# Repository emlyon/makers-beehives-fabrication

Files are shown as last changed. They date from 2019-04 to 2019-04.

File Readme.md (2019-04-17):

# Makers' Beehive

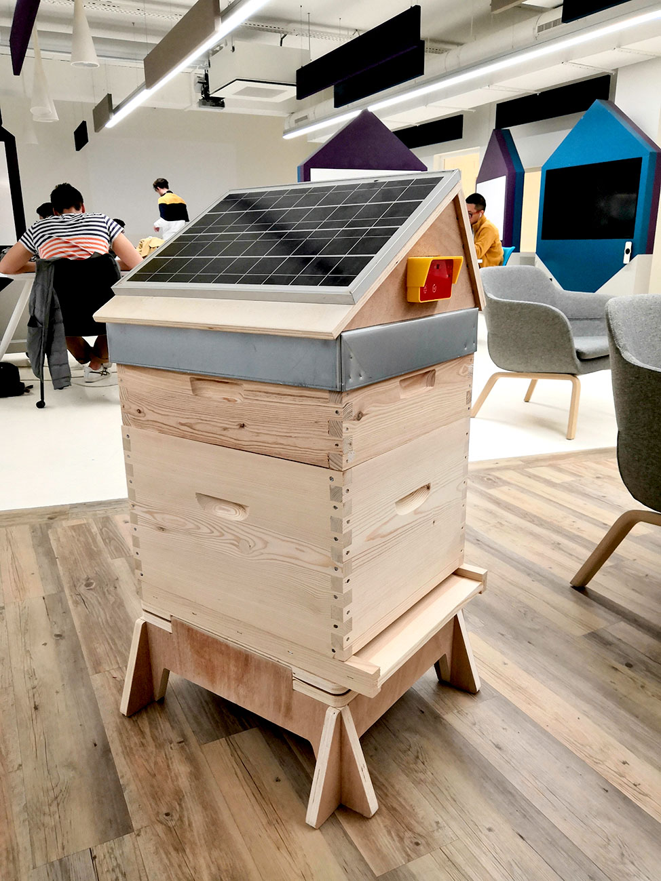
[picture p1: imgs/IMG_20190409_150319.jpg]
Makers Beehive


Makers’ Beehive is an open source beehive that was designed and
crafted at emlyon Business School’s makers’ lab during a bootcamp about IoT
by staff, students and alumni.

This project upgrades a standard dadant type beehive with load sensors on the base,
environmental sensors and camera on the roof.

More info here : [makerslab.em-lyon.com](http://makerslab.em-lyon.com/)

Makers' Beehive is licensed under the [CC by-nc-sa 4.0](https://creativecommons.org/licenses/by-nc-sa/4.0/) creative commons license



---

## Building instructions

### Electronics

Instructions for the electronics part used to monitor the activity of the beehive and the environment can be found on [this github repository](https://github.com/emlyon/makers-beehives-hardware)

---

### CNC milling

Makers Beehive has been designed to be fabricated using a CNC router with CTBX plywood 21mm.

Use a 8mm flat milling bit to cut. The [3D model](https://github.com/emlyon/makers-beehives-fabrication/blob/master/CNC%20router/makers_beehive_CNC.3dm) includes the layout for CNC milling.

We used [Autodesk Fusion 360](https://www.autodesk.com/products/fusion-360/overview) to generate the toolpaths : you can find tutorials about the _Manufacture_ feature of Fusion 360 on [Autodesk website](https://f360ap.autodesk.com/courses#creating-toolpaths-and-programs-cam).

The fusion 360 archive files are included into the [CNC router folder](https://github.com/emlyon/makers-beehives-fabrication/tree/master/CNC%20router)

---

### Assembly

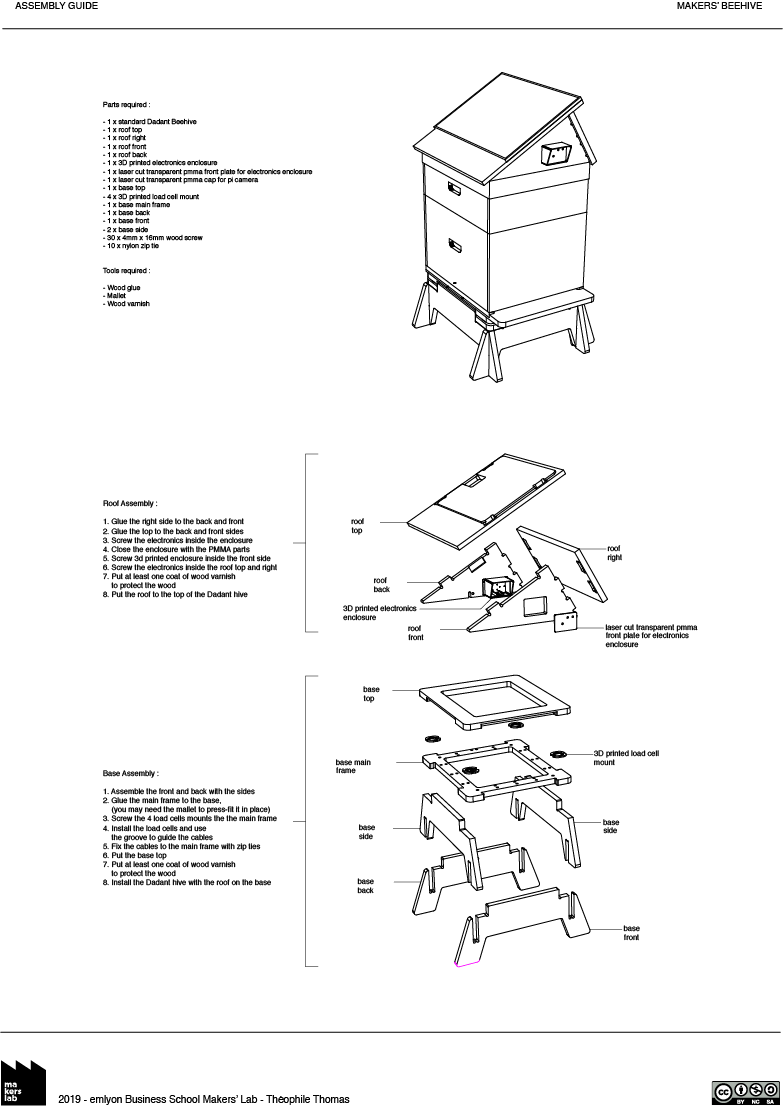
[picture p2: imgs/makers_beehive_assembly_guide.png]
Makers Beehive Assembly


A detailled list of the parts and an assembly guide can be found [in this pdf](makers_beehive_assembly_guide.pdf).

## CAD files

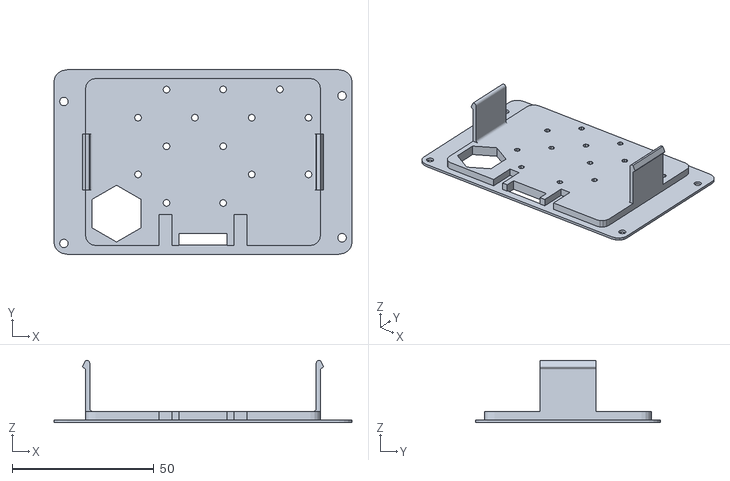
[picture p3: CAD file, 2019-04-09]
3D printing/sensor_beehive_case_base.stl
105.0 x 65.0 x 22.0

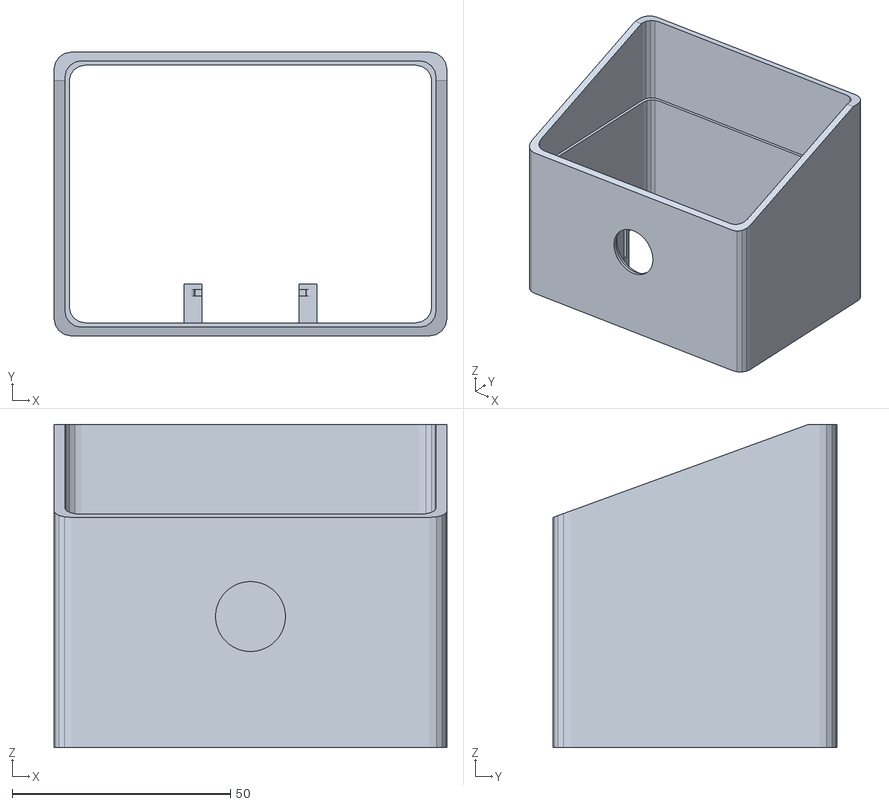
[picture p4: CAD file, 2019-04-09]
3D printing/sensor_beehive_case_top.stl
90.0 x 65.0 x 74.0

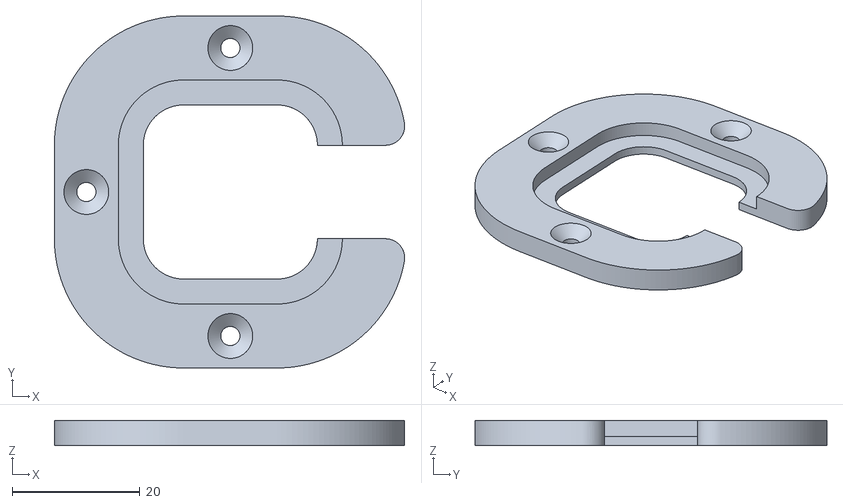
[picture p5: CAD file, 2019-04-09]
3D printing/load cell mount.stl
54.7 x 55.0 x 3.98

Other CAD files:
CNC router/baseCNC.f3d
CNC router/roofCNC.f3d

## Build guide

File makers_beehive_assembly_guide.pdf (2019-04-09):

### MAKERS’ BEEHIVE

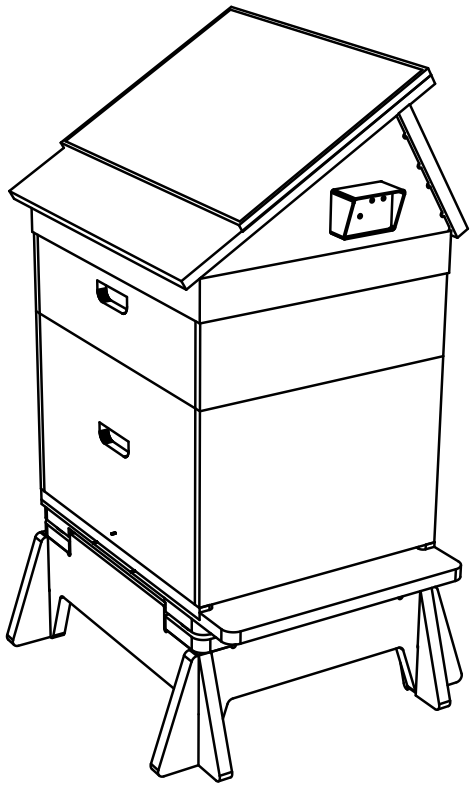
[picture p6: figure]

Parts required :
- 1 x standard Dadant Beehive
- 1 x roof top
- 1 x roof right
- 1 x roof front
- 1 x roof back
- 1 x 3D printed electronics enclosure
- 1 x laser cut transparent pmma front plate for electronics enclosure
- 1 x laser cut transparent pmma cap for pi camera
- 1 x base top
- 4 x 3D printed load cell mount
- 1 x base main frame
- 1 x base back
- 1 x base front
- 2 x base side
- 30 x 4mm x 16mm wood screw
- 10 x nylon zip tie

Tools required :
- Wood glue
- Mallet
- Wood varnish

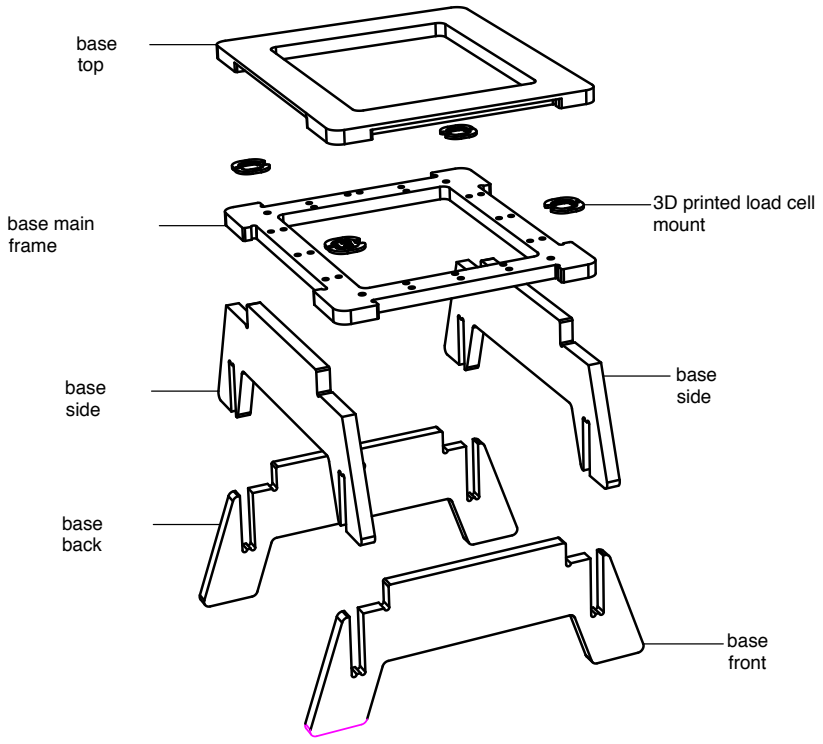
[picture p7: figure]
base top; 3D printed load cell; base main; mount; frame; base side base side; base back; base front

Base Assembly :
1. Assemble the front and back with the sides
2. Glue the main frame to the base,
(you may need the mallet to press-fit it in place)
3. Screw the 4 load cells mounts the the main frame
4. Install the load cells and use
the groove to guide the cables
5. Fix the cables to the main frame with zip ties
6. Put the base top
7. Put at least one coat of wood varnish
to protect the wood
8. Install the Dadant hive with the roof on the base

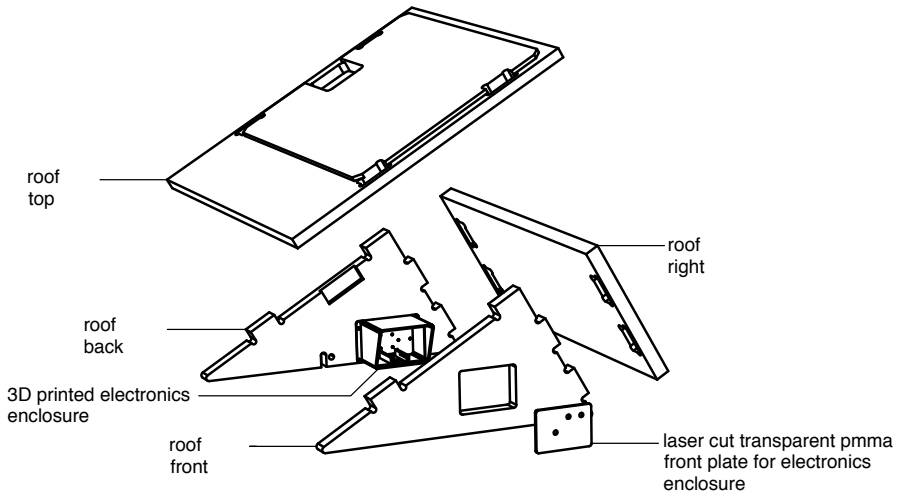
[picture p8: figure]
laser cut transparent pmma front plate for electronics enclosure; roof front; roof back; 3D printed electronics enclosure; roof right; roof top

Roof Assembly :
1. Glue the right side to the back and front
2. Glue the top to the back and front sides
3. Screw the electronics inside the enclosure
4. Close the enclosure with the PMMA parts
5. Screw 3d printed enclosure inside the front side
6. Screw the electronics inside the roof top and right
7. Put at least one coat of wood varnish
to protect the wood
8. Put the roof to the top of the Dadant hive

### ASSEMBLY GUIDE

## 2019 - emlyon Business School Makers’ Lab - Théophile Thomas

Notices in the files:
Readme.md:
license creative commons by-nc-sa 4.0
